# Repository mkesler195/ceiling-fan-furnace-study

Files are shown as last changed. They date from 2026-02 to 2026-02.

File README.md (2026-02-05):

# Ceiling Fan & Furnace Study

## Why this project exists

This project explores the real-world interaction between ceiling fan usage,
furnace runtime, and indoor temperature dynamics in a lived-in home environment.

Rather than relying solely on theoretical models, the goal is to collect
and analyze actual sensor data to better understand:
- how often and how long the furnace runs under different conditions
- whether ceiling fan operation meaningfully affects runtime or comfort
- how small environmental changes show up in logged data over time

The project emphasizes hands-on measurement, careful documentation,
and iterative analysis to surface practical insights rather than
perfect or universal conclusions.

## Overview

This repository documents an ongoing, non‑invasive study of **winter comfort, air circulation, and furnace runtime** in a residential open‑plan living space with a cathedral ceiling. The project explores how **ceiling fan mode (OFF, Counter Clockwise "CCW", or Clockwise "CW")** affects perceived comfort and air distribution *without materially changing measured room temperature*, and how those effects relate to **actual furnace operation**.

A key design principle is **separation of concerns**:

* A **basement listener** detects furnace activity acoustically (non‑invasive, no thermostat wiring).
* An **upstairs logger** records temperature, pressure, fan mode, and timestamps to understand how heat is experienced in the living space.

The goal is not to optimize HVAC controls directly, but to **observe, measure, and reason about comfort, efficiency, and air mixing** using inexpensive sensors and careful experimental design.

---

## System Architecture (High Level)

* **Basement Furnace Listener**

  * Microphone‑based acoustic detection
  * Identifies furnace ON/OFF states using peak‑to‑peak sound energy
  * Applies hysteresis to avoid false transitions
  * Sends state + acoustic data wirelessly

* **Upstairs Data Logger**

  * Receives furnace state and acoustic energy (p2p)
  * Logs indoor temperature, pressure, fan mode, and timestamps
  * Stores snapshot‑based samples to SD card

Importantly, the listener has **no awareness of ceiling fan operation**. All fan‑related effects are observed *only* in the living space data.

---

## Questions This Project Explores

* How stable is measured indoor temperature across different fan modes?
* Why can comfort change significantly even when temperature varies by only ~±1°F?
* How do FAN OFF, FAN CCW (downward airflow), and FAN CW (upward airflow) differ in perceived warmth?
* Can sample‑based logging yield useful insights without full event‑driven HVAC integration?
* What are the tradeoffs of acoustic detection and hysteresis in real homes?

---

## Repository Structure

```
ceiling-fan-furnace-study/
│
├── README.md                # This file
│
├── firmware/                # Arduino firmware
│   ├── listener/            # Basement furnace listener (mic + radio)
│   └── logger/              # Upstairs logger (temp, SD, RTC, fan mode)
│
├── hardware/                # Physical build artifacts
│   ├── fritzing/            # Fritzing diagrams and images
│   └── wiring-notes.md      # Grounding, caps, placement notes
│
├── docs/                    # Explanatory documentation
│   ├── room-layouts/        # Floor plans and sensor placement
│   ├── experimental-design/ # Assumptions, methodology, fan modes
│   ├── findings/            # Observations, interpretations, conclusions
│   └── figures/             # Charts and annotated plots
│
├── data/                    # Logged data
│   ├── raw/                 # Unmodified CSVs grouped by fan mode
│   ├── processed/           # Combined / filtered datasets
│   └── README.md            # Data naming and caveats
│
└── analysis/                # Scripts and notebooks (optional)
    ├── scripts/
    ├── notebooks/
    └── README.md
```

---

## Experimental Philosophy

* **Non‑invasive by design** — no thermostat wiring or HVAC control signals
* **Snapshot‑based sampling** rather than precise event timing
* **Relative changes matter more than absolute values**
* Comfort is treated as a **human experience**, not just a temperature number

This repository intentionally preserves *thinking*, not just results.

---

## Where to Start

1. `docs/experimental-design/` — understand the assumptions and methodology
2. `docs/room-layouts/` — see the physical context of the measurements
3. `docs/findings/` — read the emerging conclusions
4. `firmware/` — review how data is captured and transmitted

---

## Status

This is an **active, exploratory project**. Findings will evolve as additional data is collected across different times of day, outdoor temperatures, and fan configurations.

Contributions, questions, and thoughtful critique are welcome.

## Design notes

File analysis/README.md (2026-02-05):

# Analysis

This folder contains notes, interpretations, and analysis related to the
Ceiling Fan / Furnace Study.

The goal of this analysis is not just to collect data, but to understand
patterns, relationships, and implications for energy usage, comfort, and
system behavior.

## What belongs here

Examples of content in this folder include:
- Analysis assumptions and constraints
- Summaries of logged data (runtime, cycles, thresholds)
- Observations about furnace behavior under different conditions
- Comparisons between fan settings (direction, speed, on/off)
- Notes on anomalies, edge cases, or unexpected results
- Questions and hypotheses for future tests

## What does NOT belong here

- Raw firmware or Arduino sketches (see `firmware/`)
- Wiring diagrams or photos (see `docs/`)
- Raw SD card logs (stored separately or referenced as needed)

## Status

This analysis is iterative and evolving. Notes may be partial, provisional,
or revised as new data is collected.

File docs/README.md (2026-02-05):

# Documentation

This folder contains diagrams, photos, and supporting material for the
Ceiling Fan / Furnace Study.

## Fritzing
Wiring diagrams for the furnace data logger and remote listener nodes.

## Photos
Physical layout and installation reference images.

## Room Layouts

### Main Floor Layout

This diagram shows the main floor layout, including the ceiling fan,
thermostat location, and base unit placement used in the study.

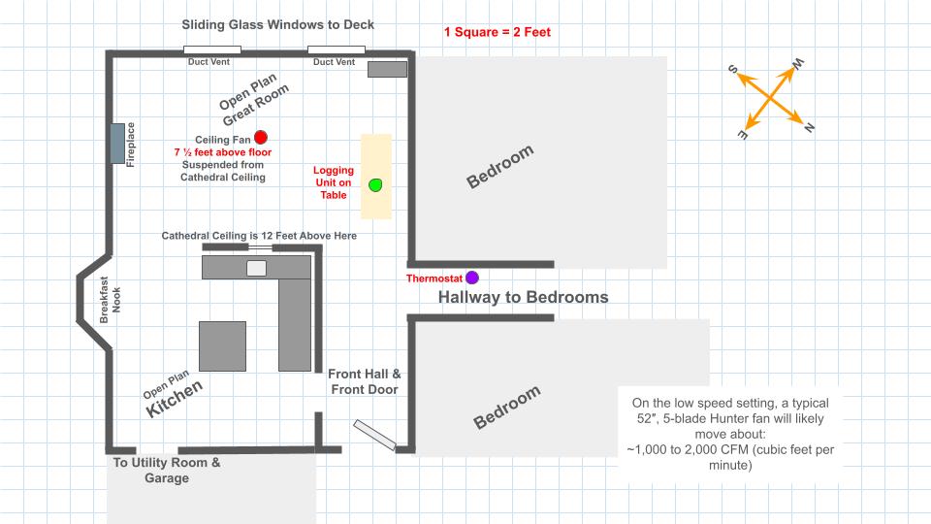
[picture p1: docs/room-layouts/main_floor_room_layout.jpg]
Main floor room layout


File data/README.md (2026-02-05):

# Data Logs (SD Card Output)

This folder contains data files written by the **base logger** to the SD card and later copied here for analysis.

The intent is to keep raw or lightly processed data alongside notes and scripts that interpret it.

## Where the data comes from

- Generated by the **upstairs base logger**
- Written to SD card during test runs
- Copied manually into this folder after retrieval

Relevant firmware:
- `firmware/logger/base_logger_sd/base_logger_sd.ino`

## Log file format (conceptual)

Log files are written in a **CSV-style** format (comma-separated values) so they can be opened in:
- spreadsheet tools
- plotting tools
- simple analysis scripts

Each row represents a single record with a timestamp.

### Typical record types

#### 1. Periodic environmental records
Logged at a regular interval.

Fields typically include:
- date
- time
- temperature (°C)
- air pressure (hPa)
- (optional) other local sensor values

Example (illustrative only):

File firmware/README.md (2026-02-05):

# Firmware Overview: Logger ↔ Listener Message Flow

This project currently has two active firmware roles:

- **Logger (upstairs)**: aggregates data and writes timestamped logs to SD card.
- **Listener (basement)**: detects furnace activity (microphone thresholds) and reports events upstream by radio.

## Where the code lives

- Logger sketch:
  - `firmware/logger/base_logger_sd/base_logger_sd.ino`

- Listener sketch:
  - `firmware/listener/basement_listener_mic/basement_listener_mic.ino`

## System topology

Basement Listener (Node)  --->  Radio (nRF24L01)  --->  Upstairs Logger (Base)
         |                                                     |
   Mic detects sound                                     RTC timestamps
   decides ON/OFF                                        SD logs records
   sends events + heartbeat                              logs Wx + events

## What gets sent over radio (conceptually)

The listener sends small messages that fall into these categories:

1. **Heartbeat** (periodic “I’m alive”)
   - Helps confirm the basement node is powered and in range

2. **Furnace ON / OFF events**
   - Listener detects sustained “loud” audio above a threshold (ON)
   - Listener detects sustained “quiet” audio below a threshold (OFF)
   - Thresholds and persistence logic live in the listener sketch

3. **(Optional / future) additional telemetry**
   - e.g., raw mic level summaries, battery voltage, local temp, etc.

> Note: The exact struct/fields are defined in the sketches. This README describes the flow and intent.

## Logger responsibilities (upstairs)

The logger is responsible for:

- Maintaining **time** (RTC) and using it for all logged records
- Writing to the **SD card** (CSV-style log files)
- Receiving radio messages and recording them as events
- (Often) also logging local environmental data (BMP280)

### Typical SD record types

- Periodic environmental log:
  - timestamp + temp + pressure (+ anything else you add later)

- Event log:
  - timestamp + event type (ON/OFF/HEARTBEAT) (+ node id / seq if used)

## Listener responsibilities (basement)

The listener is responsible for:

- Sampling microphone input
- Implementing detection logic (thresholds + persistence/hysteresis)
- Sending:
  - heartbeat messages
  - furnace ON/OFF transitions
- Remaining simple and reliable (avoid SD/logging complexity in basement)

### Detection notes

- Mic thresholds are **environment-dependent**
- Placement matters (distance to furnace, vibration coupling, etc.)
- The listener should prioritize:
  - stable classification (few false ON/OFF flips)
  - clear ON/OFF transitions over “perfect amplitude measurement”

## Packet / Protocol notes (recommended conventions)

If/when you standardize packet fields, these are useful:

- `node_id` (who sent it)
- `seq` (sequence counter; helps detect drops/repeats)
- `msg_type` (HEARTBEAT / FURNACE_ON / FURNACE_OFF)
- `payload` (optional: mic summary, battery, etc.)

If you later move shared structs into one place:
- create `firmware/common/protocol.h`
- include it from both sketches

## Quick troubleshooting checklist

- No events on SD:
  - confirm SD init succeeds in logger
  - confirm RTC time is set
  - confirm radio wiring + power (nRF24 needs solid 3.3V + capacitor)

- Listener seems dead:
  - verify heartbeat is enabled and being sent
  - check mic module power and analog pin wiring
  - confirm thresholds aren’t set so high it never triggers

- Radio flaky:
  - add / confirm local decoupling capacitor at nRF24
  - reduce data rate / adjust channel (if needed)
  - confirm CE/CSN pins match the sketch

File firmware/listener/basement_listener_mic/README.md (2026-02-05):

# Basement Furnace Listener (Mic + Radio)

## Role
This sketch runs on the **basement listener node** near the furnace.  
It detects furnace activity via microphone input and reports events upstream via radio.

## Physical Location
- Basement, near furnace

## Hardware
- Arduino (UNO / Nano — note actual board used)
- Microphone module (analog input)
- nRF24L01 radio

## Behavior
- Continuously samples microphone input
- Detects sustained sound above threshold
- Sends ON/OFF or heartbeat events to base logger

## Notes / Gotchas
- Detection thresholds are environment-dependent
- Mic sensitivity and placement matter a lot
- False positives can occur during other basement noise

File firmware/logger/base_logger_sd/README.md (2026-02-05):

# Base Logger (SD Card + RTC)

## Role
This sketch runs on the **upstairs base / logger unit**.  
It collects environmental data and event messages from remote nodes and logs them to an SD card with timestamps.

## Physical Location
- Upstairs (tabletop during testing)
- Acts as the central aggregation point for the system

## Hardware
- Arduino (UNO or Nano)
- BMP280 (temperature + air pressure)
- RTC (DS3231)
- SD card module
- nRF24L01 radio

## Behavior
- Initializes RTC, SD card, and radio
- Periodically logs timestamped environmental data
- Receives radio packets from listener nodes
- Writes structured records to SD card for later analysis

## Data Output
- CSV-style log files on SD card
- Records include date/time, temperature, pressure, and event indicators

## Notes / Gotchas
- RTC must be set at least once before meaningful logging
- SD card initialization is critical; logging halts if it fails
- Log format and intervals are defined in the sketch
- Assumes listener nodes handle their own detection thresholds

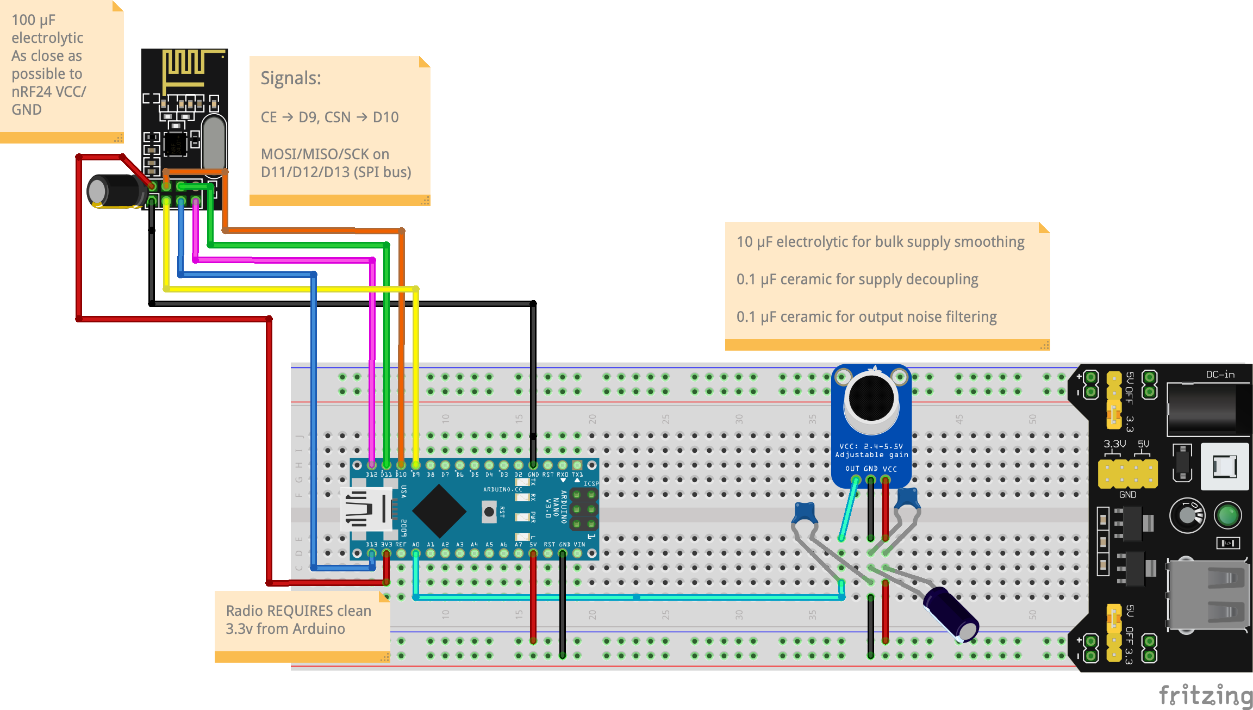
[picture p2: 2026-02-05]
docs/Fritzing/furnace-remote-listener.png

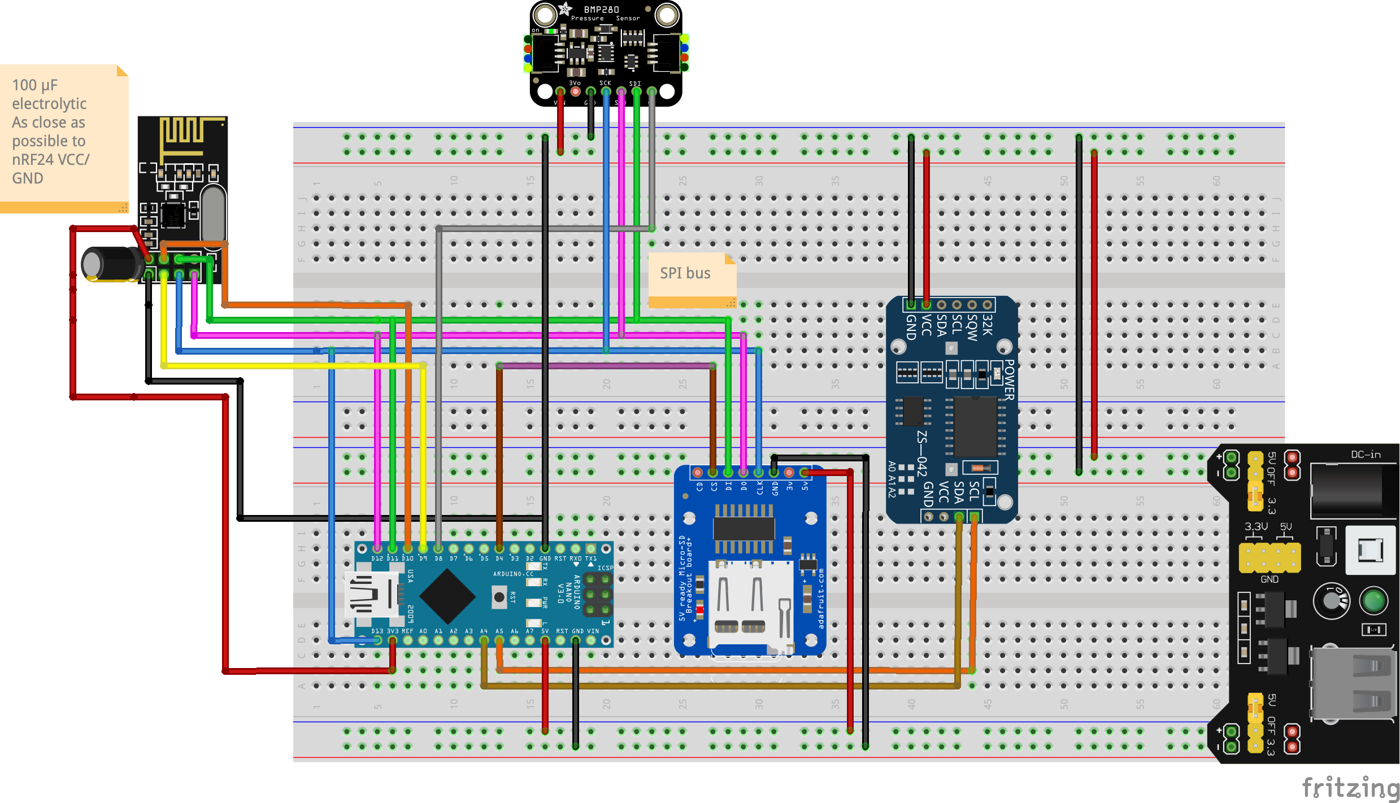
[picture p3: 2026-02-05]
docs/Fritzing/furnace-data-logger-base.png

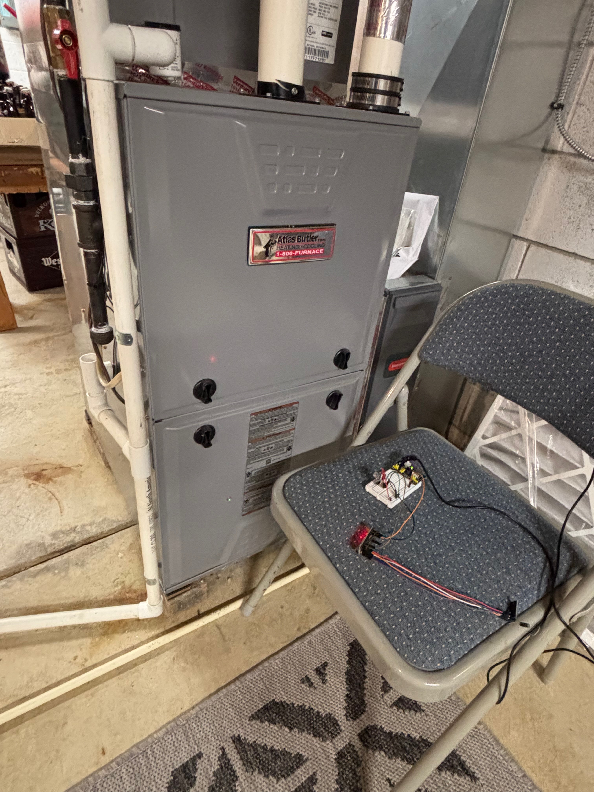
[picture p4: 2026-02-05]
docs/Photos/remote_listener_in_basement.jpeg

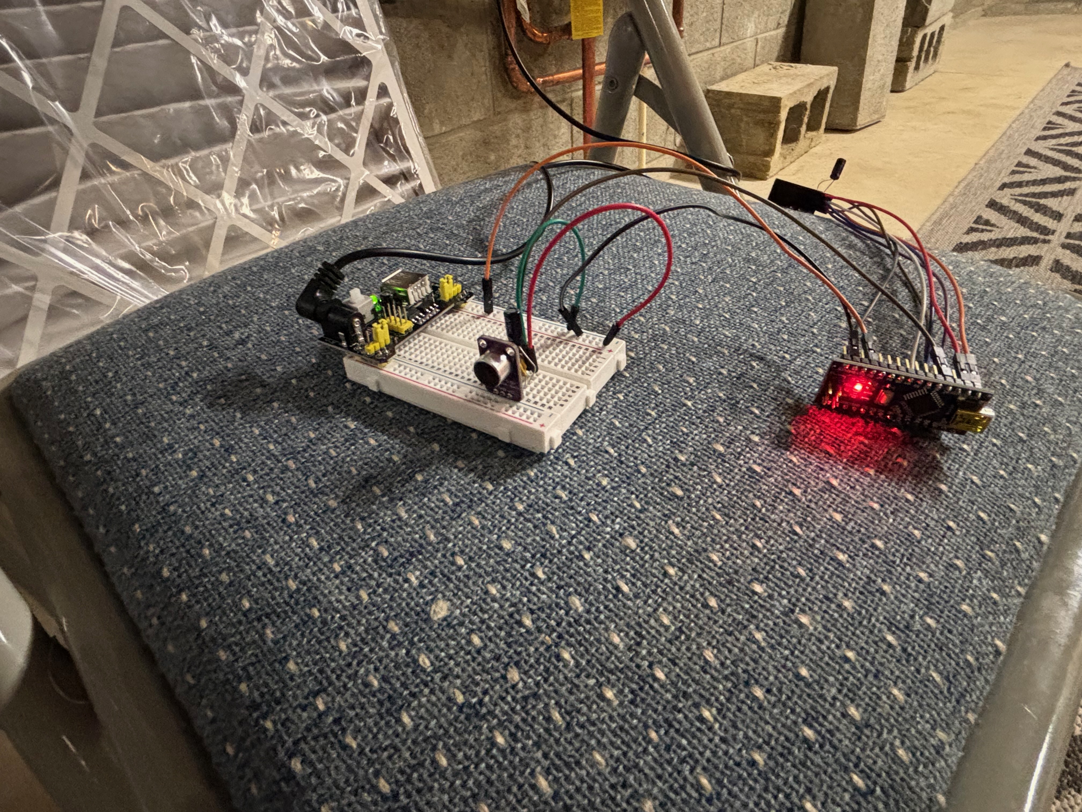
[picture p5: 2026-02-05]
docs/Photos/remote_listener_on_padded_chair.jpeg

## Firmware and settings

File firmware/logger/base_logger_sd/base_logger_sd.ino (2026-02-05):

/*
  FINAL LOGGER (Fan + Furnace + BMP + SD + RTC + LINK HEALTH + SETPOINT)

  Manual serial input:
    fan off | fan cw | fan ccw
    out <temp>
    set <temp>

  Timed logging:
    mins <n>   -> log for n minutes (starting now)
    start      -> resume logging (no time limit)
    stop       -> stop logging (no SD rows)

  Logs periodic rows (not event-only).

  Packet hardening:
    - Adds magic byte 0xA5 for validation
    - Includes furnaceOn state in EVERY packet (incl heartbeat)
    - Logger updates furnaceOn from every valid packet

  Enhancement:
    - Tracks lastStateEvt separately (only updates on evt=1 or evt=2)
*/

#include <SPI.h>
#include <Wire.h>
#include <SD.h>
#include <NRFLite.h>
#include <RTClib.h>
#include <Adafruit_BMP280.h>

// ---------------- Pins ----------------
const uint8_t PIN_SD_CS     = 4;
const uint8_t PIN_BMP_CS    = 8;
const uint8_t PIN_RADIO_CE  = 9;
const uint8_t PIN_RADIO_CSN = 10;

// ---------------- IDs ----------------
const uint8_t LOGGER_NODE_ID   = 0;
const uint8_t LISTENER_NODE_ID = 2; // Basement listener node

// ---------------- Timing ----------------
const uint32_t STATUS_EVERY_MS = 10000;   // status print
const uint32_t LOG_EVERY_MS    = 60000;   // 1 minute logging

// ---------------- Objects ----------------
NRFLite radio;
RTC_DS3231 rtc;
Adafruit_BMP280 bmp(PIN_BMP_CS);

// ---------------- State ----------------
enum FanMode : uint8_t { FAN_OFF=0, FAN_CW=1, FAN_CCW=2 };
FanMode fanMode = FAN_OFF;

float outdoorTemp = NAN;
float setTemp     = NAN;

bool furnaceOn = false;

// Radio health (last packet)
bool     haveRx   = false;
uint32_t lastRxMs = 0;
uint8_t  lastEvt  = 0;
uint16_t lastP2P  = 0;
uint16_t lastSeq  = 0;

// NEW: last *state-change* event only (evt 1 or 2)
bool     haveStateEvt   = false;
uint8_t  lastStateEvt   = 0;  // 1=ON, 2=OFF
uint32_t lastStateEvtMs = 0;

// ---------------- Logging ----------------
const char* LOG_FILE = "wxlog.csv";

// Timed logging control
bool     loggingEnabled = true;   // default: logging ON
bool     timedMode      = false;  // true if mins <n> was set
uint32_t logEndMs       = 0;      // millis() at which timed logging ends
bool     printedDone    = false;  // ensure we print "done" once

// ---------------- Packet (MUST match listener) ----------------
struct FurnacePkt {
  uint8_t  magic;     // 0xA5
  uint8_t  nodeId;    // 2
  uint8_t  eventType; // 1=ON, 2=OFF, 3=HEARTBEAT
  uint8_t  furnaceOn; // 0/1 (ALWAYS current state)
  uint16_t seq;
  uint16_t p2p;
};

// ---------------- Helpers ----------------
void deselectAllSPI() {
  pinMode(PIN_SD_CS, OUTPUT);     digitalWrite(PIN_SD_CS, HIGH);
  pinMode(PIN_BMP_CS, OUTPUT);    digitalWrite(PIN_BMP_CS, HIGH);
  pinMode(PIN_RADIO_CSN, OUTPUT); digitalWrite(PIN_RADIO_CSN, HIGH);
}

String ts(const DateTime& dt) {
  char buf[20];
  snprintf(buf, sizeof(buf), "%04d-%02d-%02d %02d:%02d:%02d",
           dt.year(), dt.month(), dt.day(),
           dt.hour(), dt.minute(), dt.second());
  return String(buf);
}

void writeHeaderIfNeeded() {
  if (!SD.exists(LOG_FILE)) {
    File f = SD.open(LOG_FILE, FILE_WRITE);
    if (f) {
      // NEW: add lastStateEvt as one extra column (end)
      f.println(F("datetime,fanMode,outdoorTemp,setTemp,furnaceOn,tempC,press_hPa,linkAgeSec,lastEvt,lastSeq,p2p,lastStateEvt"));
      f.close();
      Serial.println(F("[SD] Header OK"));
    } else {
      Serial.println(F("[SD] Header write FAIL"));
    }
  }
}

// ---------------- Setup ----------------
void setup() {
  Serial.begin(115200);
  delay(200);

  Serial.println();
  Serial.println(F("=== FINAL LOGGER (Fan + Furnace + BMP + SD + RTC + LINK HEALTH + SETPOINT) ==="));

  Wire.begin();
  SPI.begin();
  deselectAllSPI();

  // RTC
  if (rtc.begin()) {
    Serial.print(F("[RTC] OK: "));
    Serial.println(ts(rtc.now()));
  } else {
    Serial.println(F("[RTC] FAIL"));
  }

  // BMP
  if (bmp.begin()) {
    Serial.println(F("[BMP] OK"));
  } else {
    Serial.println(F("[BMP] FAIL"));
  }

  // SD
  if (SD.begin(PIN_SD_CS)) {
    Serial.println(F("[SD] OK"));
    writeHeaderIfNeeded();
  } else {
    Serial.println(F("[SD] FAIL"));
  }

  // Radio
  if (radio.init(LOGGER_NODE_ID, PIN_RADIO_CE, PIN_RADIO_CSN)) {
    Serial.println(F("[RADIO] OK (listening)"));
  } else {
    Serial.println(F("[RADIO] FAIL: radio.init()"));
  }

  Serial.println(F("Type: fan off | fan cw | fan ccw | out <temp> | set <temp> | mins <n> | start | stop"));
}

// ---------------- Serial Input ----------------
void handleSerial() {
  if (!Serial.available()) return;

  String cmd = Serial.readStringUntil('\n');
  cmd.trim();
  cmd.toLowerCase();

  if (cmd == "fan off") {
    fanMode = FAN_OFF;
    Serial.println(F("[INPUT] Fan = OFF"));
  } else if (cmd == "fan cw") {
    fanMode = FAN_CW;
    Serial.println(F("[INPUT] Fan = CW"));
  } else if (cmd == "fan ccw") {
    fanMode = FAN_CCW;
    Serial.println(F("[INPUT] Fan = CCW"));
  } else if (cmd.startsWith("out ")) {
    outdoorTemp = cmd.substring(4).toFloat();
    Serial.print(F("[INPUT] Outdoor temp = "));
    Serial.println(outdoorTemp, 2);
  } else if (cmd.startsWith("set ")) {
    setTemp = cmd.substring(4).toFloat();
    Serial.print(F("[INPUT] Setpoint = "));
    Serial.println(setTemp, 2);
  } else if (cmd.startsWith("mins ")) {
    int mins = cmd.substring(5).toInt();
    if (mins <= 0) {
      Serial.println(F("[INPUT] mins must be > 0"));
      return;
    }
    timedMode = true;
    loggingEnabled = true;
    printedDone = false;
    uint32_t nowMs = millis();
    logEndMs = nowMs + (uint32_t)mins * 60000UL;

    Serial.print(F("[INPUT] Timed logging for "));
    Serial.print(mins);
    Serial.println(F(" minute(s)."));
  } else if (cmd == "stop") {
    loggingEnabled = false;
    timedMode = false;
    Serial.println(F("[INPUT] Logging STOPPED (no SD rows will be written)."));
  } else if (cmd == "start") {
    loggingEnabled = true;
    timedMode = false;
    printedDone = false;
    Serial.println(F("[INPUT] Logging STARTED (no time limit)."));
  } else {
    Serial.println(F("[INPUT] Unknown. Try: fan off | fan cw | fan ccw | out <temp> | set <temp> | mins <n> | start | stop"));
  }
}

// ---------------- Loop ----------------
void loop() {
  handleSerial();

  uint32_t nowMs = millis();
  DateTime now = rtc.now();

  // -------- Timed logging cutoff --------
  if (timedMode && loggingEnabled) {
    // signed compare handles millis() wrap safely
    if ((int32_t)(nowMs - logEndMs) >= 0) {
      loggingEnabled = false;
      timedMode = false;
      if (!printedDone) {
        printedDone = true;
        Serial.print(F("[LOG] Timed run complete @ "));
        Serial.println(ts(now));
      }
    }
  }

  // -------- Radio RX --------
  while (radio.hasData()) {
    FurnacePkt pkt;
    radio.readData(&pkt);

    // Validate packet
    if (pkt.magic != 0xA5) {
      Serial.println(F("[RX] Ignored (bad magic)"));
      continue;
    }
    if (pkt.nodeId != LISTENER_NODE_ID) {
      Serial.println(F("[RX] Ignored (wrong node)"));
      continue;
    }
    if (pkt.eventType < 1 || pkt.eventType > 3) {
      Serial.println(F("[RX] Ignored (bad evt)"));
      continue;
    }

    haveRx   = true;
    lastRxMs = nowMs;
    lastEvt  = pkt.eventType;
    lastP2P  = pkt.p2p;
    lastSeq  = pkt.seq;

    // KEY: update furnace state on EVERY valid packet (incl heartbeat)
    furnaceOn = (pkt.furnaceOn != 0);

    // ----- State change announcement -----
  if (pkt.eventType == 1 || pkt.eventType == 2) {
  lastStateEvt = pkt.eventType;

  Serial.print(F("*** STATE CHANGE: "));
  if (pkt.eventType == 1) {
    Serial.println(F("OFF -> ON ***"));
  } else {
    Serial.println(F("ON -> OFF ***"));
  }
}

    // NEW: update lastStateEvt only on actual state-change events
    if (pkt.eventType == 1 || pkt.eventType == 2) {
      haveStateEvt = true;
      lastStateEvt = pkt.eventType;
      lastStateEvtMs = nowMs;
    }

    Serial.print(F("[RX] node="));
    Serial.print(pkt.nodeId);
    Serial.print(F(" evt="));
    Serial.print(pkt.eventType);
    Serial.print(F(" seq="));
    Serial.print(pkt.seq);
    Serial.print(F(" p2p="));
    Serial.print(pkt.p2p);
    Serial.print(F(" furnaceOn="));
    Serial.println(furnaceOn);
  }

  // -------- Status --------
  static uint32_t lastStatusMs = 0;
  if (nowMs - lastStatusMs >= STATUS_EVERY_MS) {
    lastStatusMs = nowMs;

    Serial.print(F("[STATUS] "));
    Serial.print(ts(now));
    Serial.print(F(" fan="));
    Serial.print(fanMode);

    Serial.print(F(" out="));
    if (isnan(outdoorTemp)) Serial.print(F("nan"));
    else Serial.print(outdoorTemp, 2);

    Serial.print(F(" set="));
    if (isnan(setTemp)) Serial.print(F("nan"));
    else Serial.print(setTemp, 2);

    Serial.print(F(" furnaceOn="));
    Serial.print(furnaceOn ? 1 : 0);

    if (!haveRx) {
      Serial.print(F(" link=NO_RX_YET"));
    } else {
      Serial.print(F(" link="));
      Serial.print((nowMs - lastRxMs) / 1000);
      Serial.print(F("s ago evt="));
      Serial.print(lastEvt);
      Serial.print(F(" seq="));
      Serial.print(lastSeq);
      Serial.print(F(" p2p="));
      Serial.print(lastP2P);
    }

    // NEW: show lastStateEvt (the “real” ON/OFF transition)
    Serial.print(F(" lastStateEvt="));
    if (!haveStateEvt) Serial.print(F("none"));
    else Serial.print(lastStateEvt);

    // show logging state
    Serial.print(F(" logging="));
    Serial.print(loggingEnabled ? F("ON") : F("OFF"));
    if (timedMode && loggingEnabled) {
      uint32_t remainSec = (logEndMs - nowMs) / 1000;
      Serial.print(F(" remainSec="));
      Serial.print(remainSec);
    }

    Serial.println();
  }

  // -------- Logging --------
  static uint32_t lastLogMs = 0;
  if (loggingEnabled && (nowMs - lastLogMs >= LOG_EVERY_MS)) {
    lastLogMs = nowMs;

    float tempC = bmp.readTemperature();
    float press = bmp.readPressure() / 100.0f;

    File f = SD.open(LOG_FILE, FILE_WRITE);
    if (f) {
      f.print(ts(now)); f.print(',');
      f.print(fanMode); f.print(',');

      if (isnan(outdoorTemp)) f.print("nan"); else f.print(outdoorTemp, 2);
      f.print(',');

      if (isnan(setTemp)) f.print("nan"); else f.print(setTemp, 2);
      f.print(',');

      f.print(furnaceOn ? 1 : 0); f.print(',');
      f.print(tempC, 2); f.print(',');
      f.print(press, 2); f.print(',');

      if (!haveRx) f.print("nan");
      else f.print((nowMs - lastRxMs) / 1000);
      f.print(',');

      f.print(lastEvt); f.print(',');
      f.print(lastSeq); f.print(',');
      f.print(lastP2P); f.print(',');

      // NEW: one extra field – lastStateEvt
      if (!haveStateEvt) f.println("nan");
      else f.println(lastStateEvt);

      f.close();

      Serial.print(F("[LOG] Row written @ "));
      Serial.println(ts(now));
    } else {
      Serial.println(F("[SD] Write FAIL"));
    }
  }
}

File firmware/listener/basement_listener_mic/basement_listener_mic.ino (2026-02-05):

#include <SPI.h>
#include <NRFLite.h>

NRFLite radio;

// --------- IDs ----------
const uint8_t NODE_ID = 2;
const uint8_t DEST_ID = 0;

// --------- Pins ----------
const uint8_t MIC_PIN = A0;

// --------- Mic sampling ----------
const uint16_t P2P_WINDOW_MS   = 100;
const uint16_t SAMPLE_EVERY_MS = 250;

// --------- Detection thresholds (your updated values) ----------
const uint16_t LOUD_THR_ON  = 120;
const uint16_t LOUD_THR_OFF = 100;

// --------- Persistence window ----------
const uint8_t  WINDOW_SAMPLES = 40;   // 10s
const uint8_t  ON_COUNT_THR   = 26;
const uint8_t  OFF_COUNT_THR  = 12;

const uint32_t MIN_STATE_HOLD_MS = 5000;

// --------- Heartbeat ----------
const bool ENABLE_HEARTBEAT = true;
const uint32_t HEARTBEAT_ON_MS  = 15000;
const uint32_t HEARTBEAT_OFF_MS = 60000;

// --------- Packet (MUST match logger) ----------
struct FurnacePkt {
  uint8_t  magic;     // 0xA5
  uint8_t  nodeId;
  uint8_t  eventType; // 1=ON, 2=OFF, 3=HEARTBEAT
  uint8_t  furnaceOn; // ALWAYS current state
  uint16_t seq;
  uint16_t p2p;
};

uint16_t seqCounter = 0;

// Rolling window ring buffer of 0/1 loud samples
uint8_t ring[WINDOW_SAMPLES];
uint8_t ringIdx = 0;
uint16_t loudSum = 0;

enum FurnaceState : uint8_t { STATE_OFF = 0, STATE_ON = 1 };
FurnaceState state = STATE_OFF;

uint32_t lastSampleMs = 0;
uint32_t lastStateChangeMs = 0;
uint32_t lastHeartbeatMs = 0;

int readPeakToPeak(uint16_t windowMs) {
  uint32_t start = millis();
  int minV = 1023;
  int maxV = 0;
  while ((uint32_t)(millis() - start) < windowMs) {
    int v = analogRead(MIC_PIN);
    if (v < minV) minV = v;
    if (v > maxV) maxV = v;
  }
  return maxV - minV;
}

void pushLoudSample(uint8_t isLoud) {
  loudSum -= ring[ringIdx];
  ring[ringIdx] = isLoud;
  loudSum += isLoud;
  ringIdx = (ringIdx + 1) % WINDOW_SAMPLES;
}

void sendEvent(uint8_t eventType, uint16_t p2p) {
  FurnacePkt pkt;
  pkt.magic     = 0xA5;
  pkt.nodeId    = NODE_ID;
  pkt.eventType = eventType;
  pkt.furnaceOn = (state == STATE_ON) ? 1 : 0;   // <- key change
  pkt.seq       = ++seqCounter;
  pkt.p2p       = p2p;

  bool ok = radio.send(DEST_ID, &pkt, sizeof(pkt));

  Serial.print(F("[RADIO] evt="));
  Serial.print(pkt.eventType);
  Serial.print(F(" furnaceOn="));
  Serial.print(pkt.furnaceOn);
  Serial.print(F(" seq="));
  Serial.print(pkt.seq);
  Serial.print(F(" p2p="));
  Serial.print(pkt.p2p);
  Serial.print(F(" ok="));
  Serial.println(ok ? F("1") : F("0"));
}

void setup() {
  Serial.begin(115200);
  delay(200);

  Serial.println();
  Serial.println(F("=== BASEMENT FURNACE LISTENER (Mic + NRFLite TX) ==="));

  for (uint8_t i = 0; i < WINDOW_SAMPLES; i++) ring[i] = 0;
  loudSum = 0;

  if (!radio.init(NODE_ID, 9, 10)) {
    Serial.println(F("[RADIO] FAIL: radio.init()"));
    while (1) delay(1000);
  }
  Serial.println(F("[RADIO] PASS: init ok"));

  lastSampleMs = millis();
  lastStateChangeMs = millis();
  lastHeartbeatMs = millis();
}

void loop() {
  uint32_t now = millis();

  if ((uint32_t)(now - lastSampleMs) >= SAMPLE_EVERY_MS) {
    lastSampleMs = now;

    uint16_t p2p = (uint16_t)readPeakToPeak(P2P_WINDOW_MS);

    uint8_t isLoud = 0;
    if (state == STATE_OFF) isLoud = (p2p >= LOUD_THR_ON) ? 1 : 0;
    else                   isLoud = (p2p >= LOUD_THR_OFF) ? 1 : 0;

    pushLoudSample(isLoud);

    // Debug
    Serial.print(F("p2p=")); Serial.print(p2p);
    Serial.print(F(" loudSum=")); Serial.print(loudSum);
    Serial.print(F(" state=")); Serial.print(state == STATE_ON ? F("ON") : F("OFF"));
    Serial.print(F(" isLoud=")); Serial.println(isLoud);

    bool canChange = ((uint32_t)(now - lastStateChangeMs) >= MIN_STATE_HOLD_MS);

    if (state == STATE_OFF) {
      if (canChange && loudSum >= ON_COUNT_THR) {
        state = STATE_ON;
        lastStateChangeMs = now;
        lastHeartbeatMs = now;
        Serial.println(F("*** STATE CHANGE: OFF -> ON ***"));
        sendEvent(1, p2p);
      }
    } else {
      if (canChange && loudSum <= OFF_COUNT_THR) {
        state = STATE_OFF;
        lastStateChangeMs = now;
        lastHeartbeatMs = now;
        Serial.println(F("*** STATE CHANGE: ON -> OFF ***"));
        sendEvent(2, p2p);
      }
    }

    if (ENABLE_HEARTBEAT) {
      uint32_t hbInterval = (state == STATE_ON) ? HEARTBEAT_ON_MS : HEARTBEAT_OFF_MS;
      if ((uint32_t)(now - lastHeartbeatMs) >= hbInterval) {
        lastHeartbeatMs = now;
        sendEvent(3, p2p); // now includes furnaceOn every time
      }
    }
  }
}

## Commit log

2026-02-05 Add logger and listener Arduino sketches
2026-02-05 Add firmware overview and logger-listener message flow
2026-02-05 Add Fritzing diagrams and photos to docs
    [furnace-data-logger-base.fzz, furnace-remote-listener.fzz]
